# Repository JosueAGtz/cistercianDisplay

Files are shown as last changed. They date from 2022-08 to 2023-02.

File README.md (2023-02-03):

## Single color Cistercian Display
31 segments digital Cistercian Display with constant current serial to parallel driver. If you need more info please visit my blog https://savageelectronics.com/cistercian-display/

## RGB Cistercian Display
31 Segments RGB Cistercian Display with cascade SK6812 LEDs.

displayPhoto

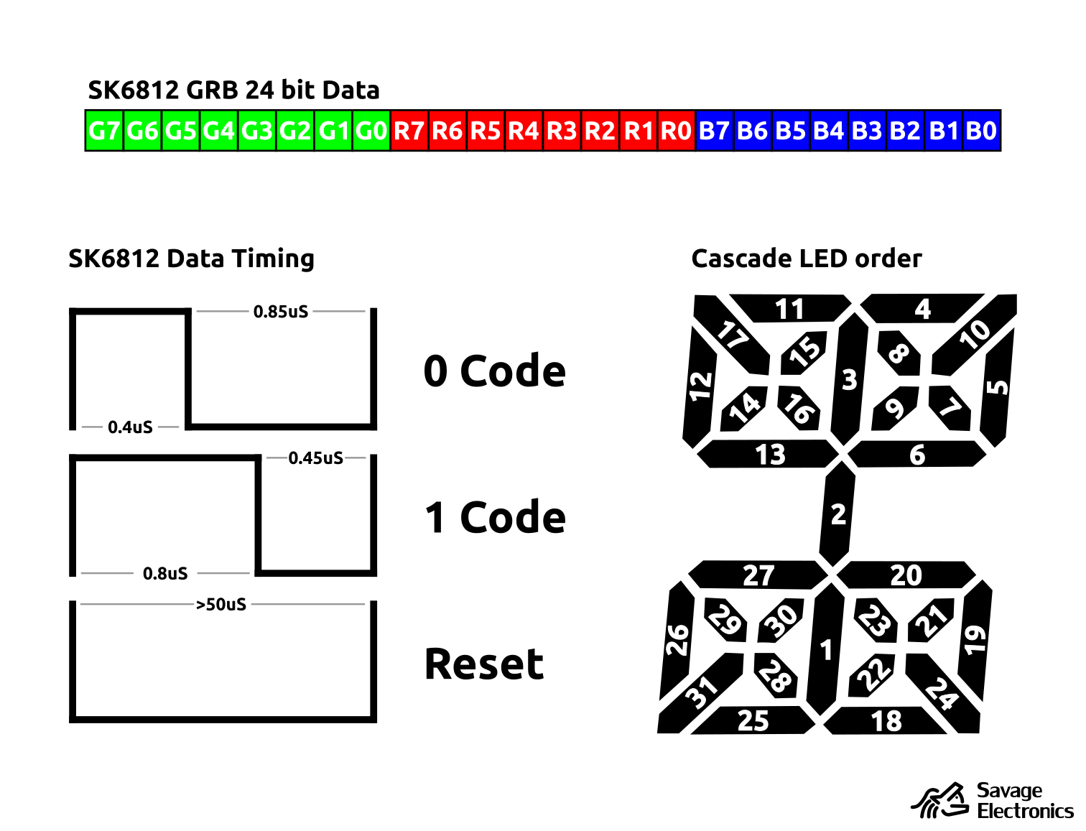
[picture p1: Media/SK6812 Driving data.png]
displayDriving


## Cistercian Display Decode
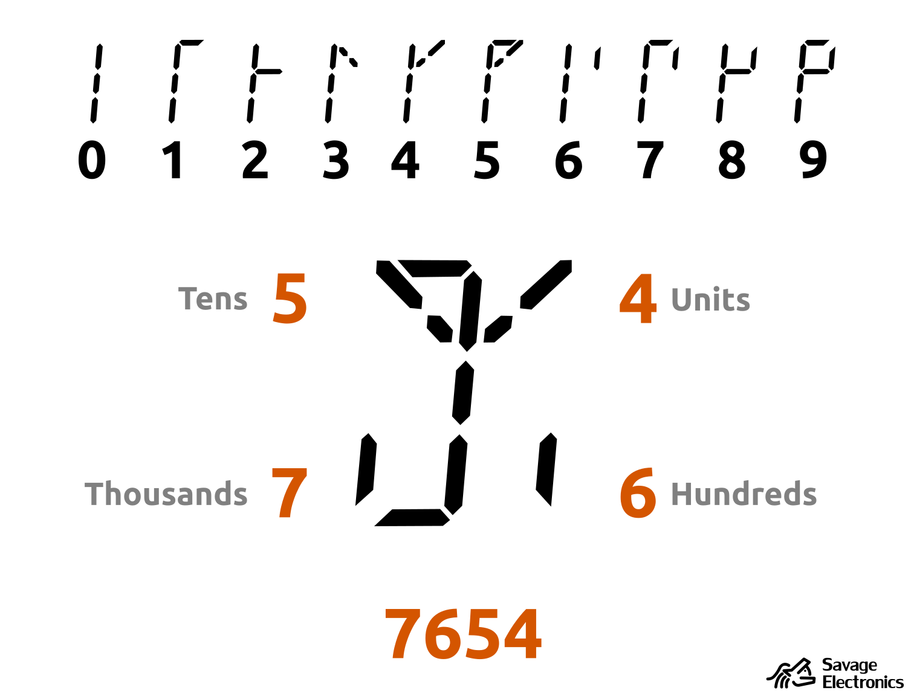
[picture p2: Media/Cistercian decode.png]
displayDecode


## RGB Cistercian Display Dimensions and Pinout
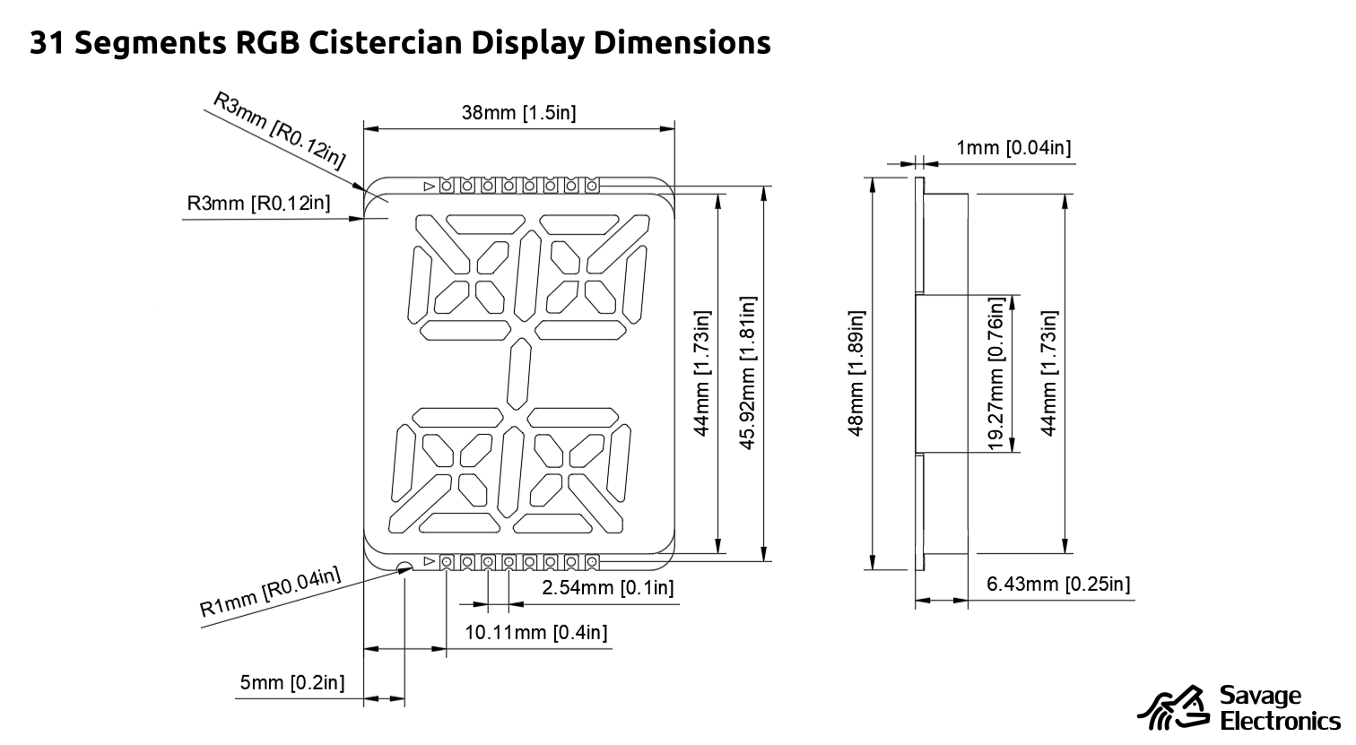
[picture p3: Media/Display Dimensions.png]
displayDimensions

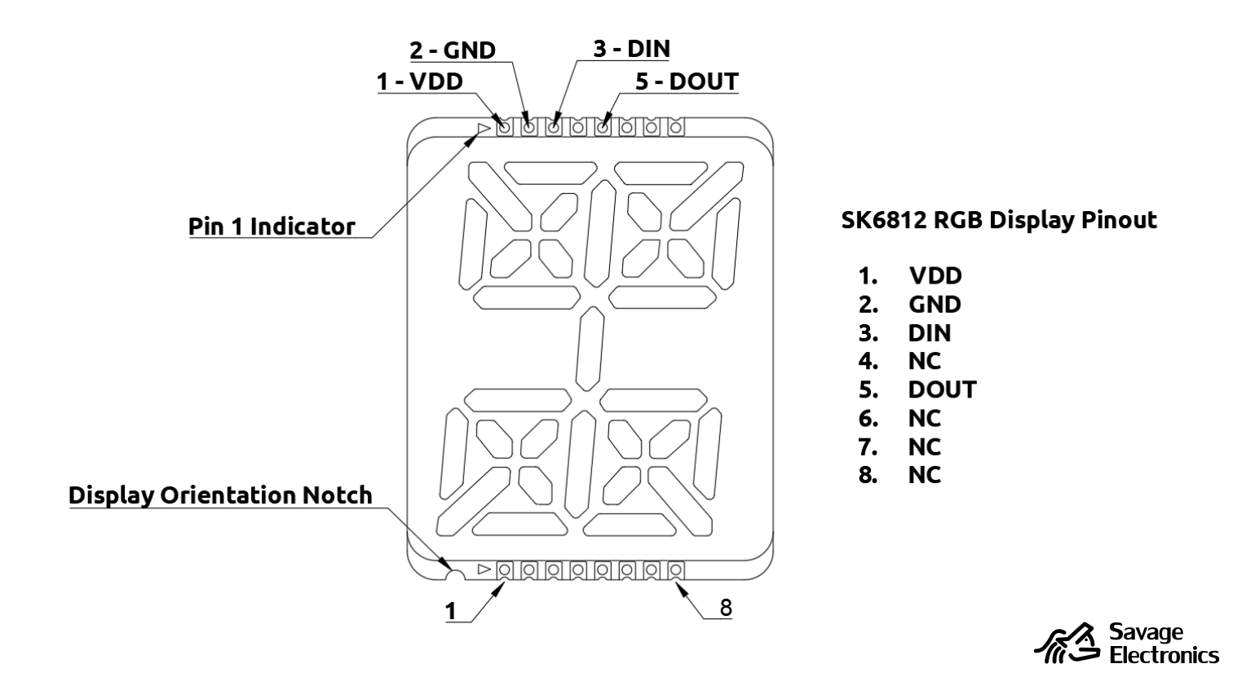
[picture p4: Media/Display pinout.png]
displayPinout


## Cistercian Display 3D Model
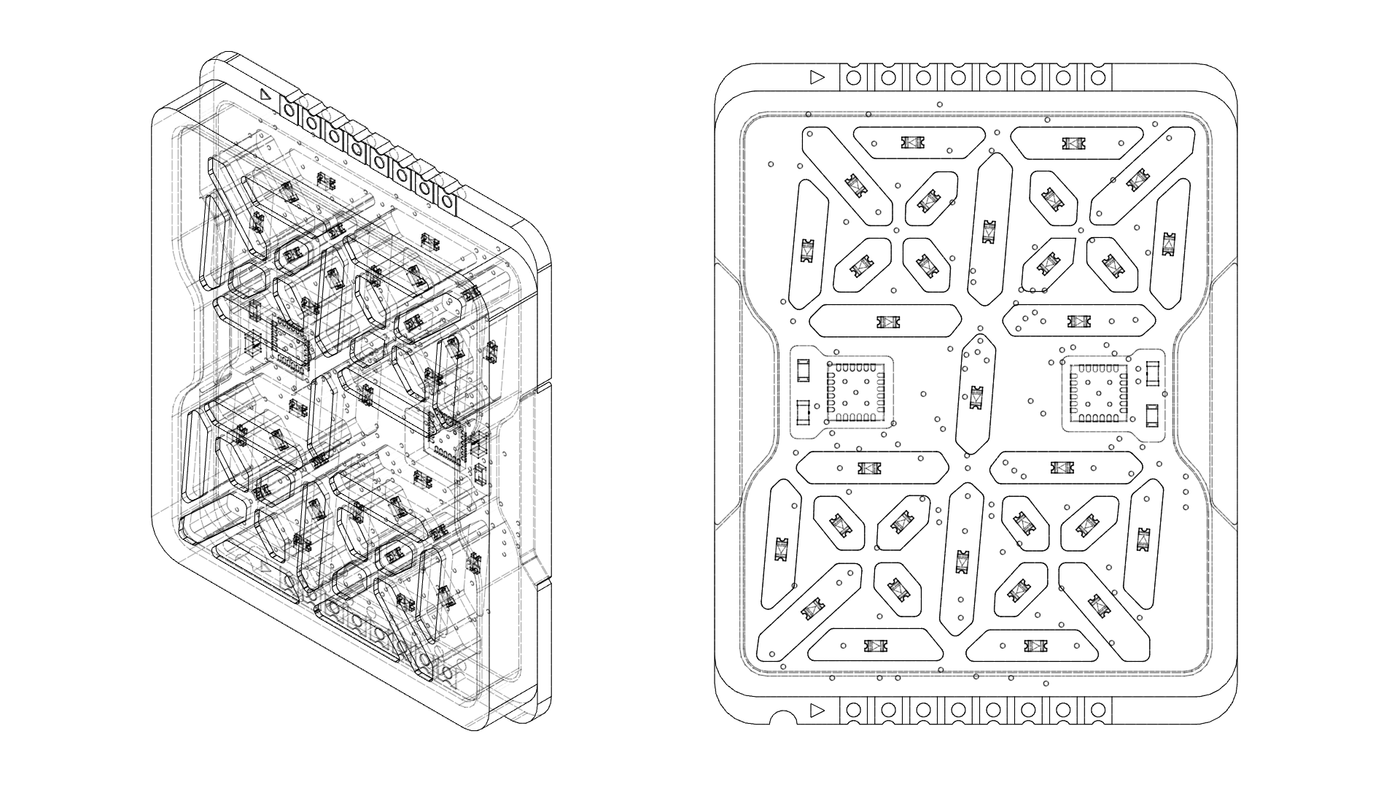
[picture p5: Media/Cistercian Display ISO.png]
displayISOMesh

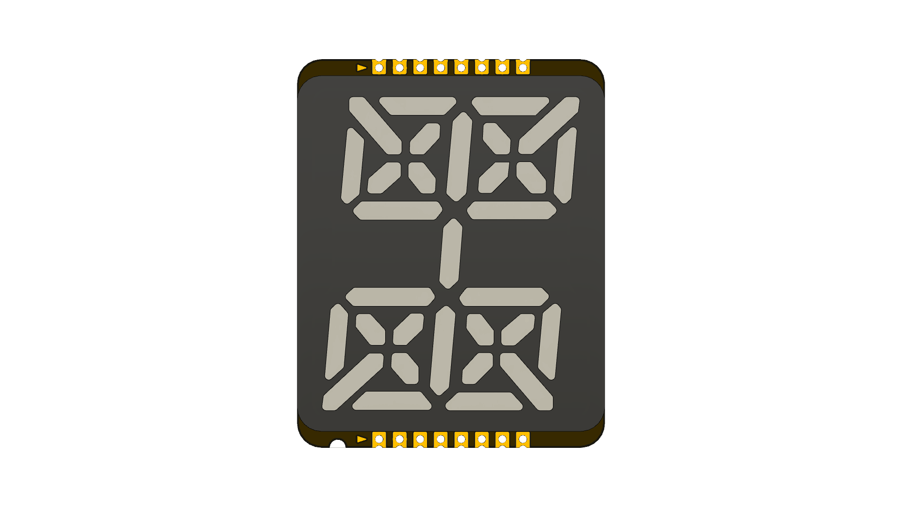
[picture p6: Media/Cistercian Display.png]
display3D


## Cistercian Display Schematic
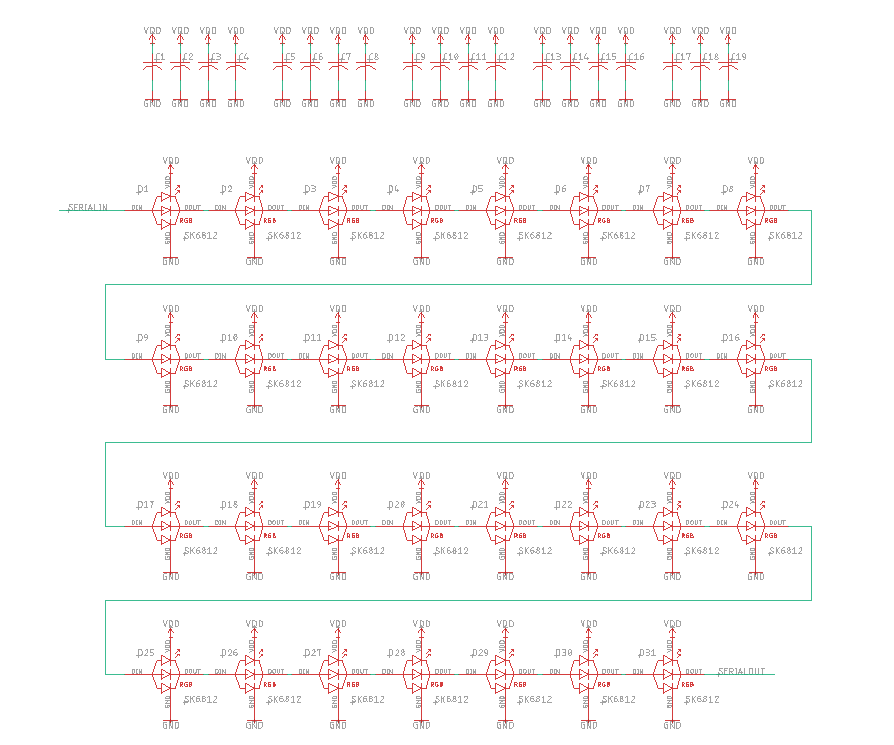
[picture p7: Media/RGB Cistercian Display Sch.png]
displayRGBSCH

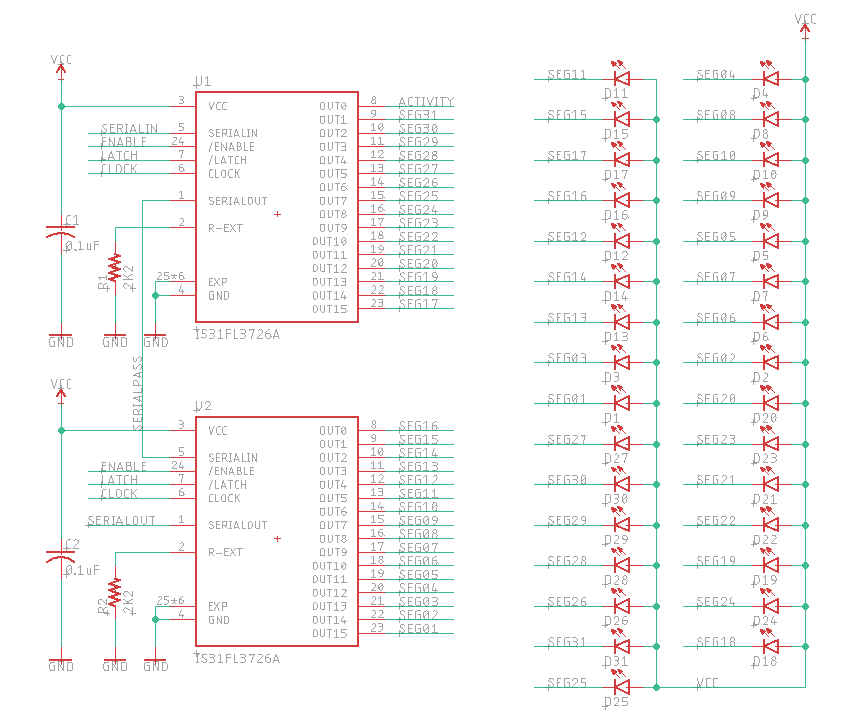
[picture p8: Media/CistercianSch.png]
displaySCH


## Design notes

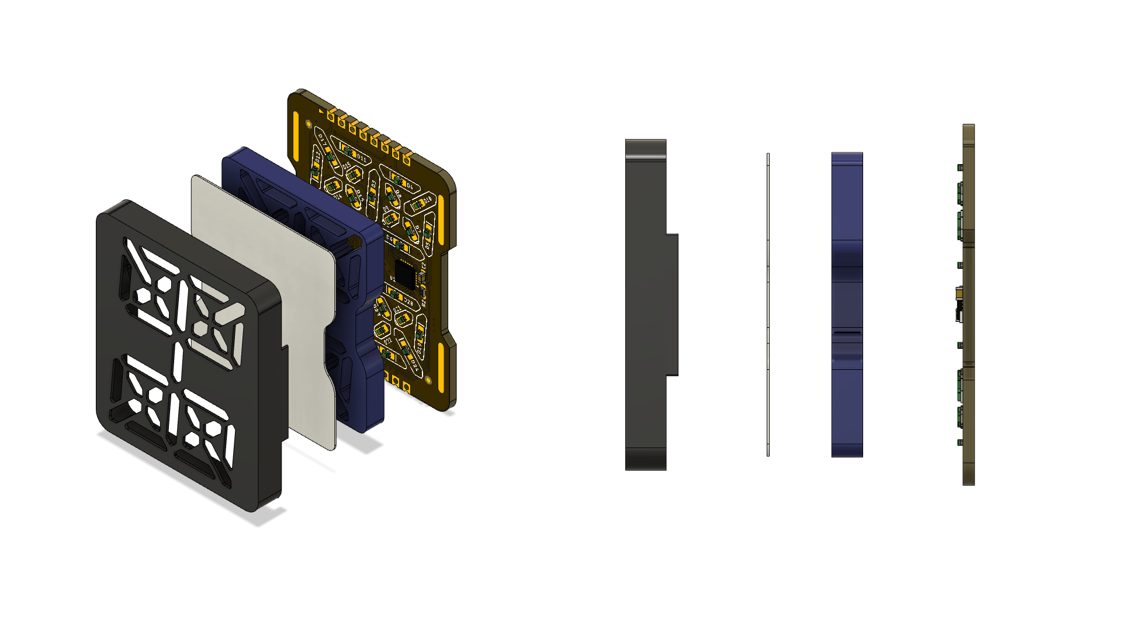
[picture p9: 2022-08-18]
Media/Cistercian Display Explode.png

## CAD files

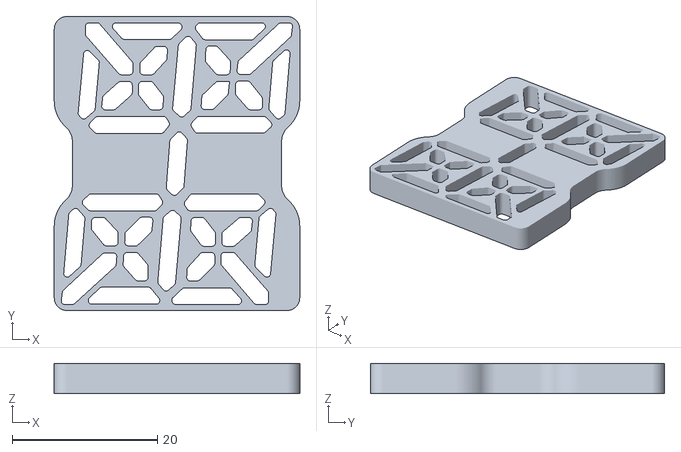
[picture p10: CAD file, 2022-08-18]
Hardware/CDisplay Spacer.stl
33.8 x 40.5 x 4.15

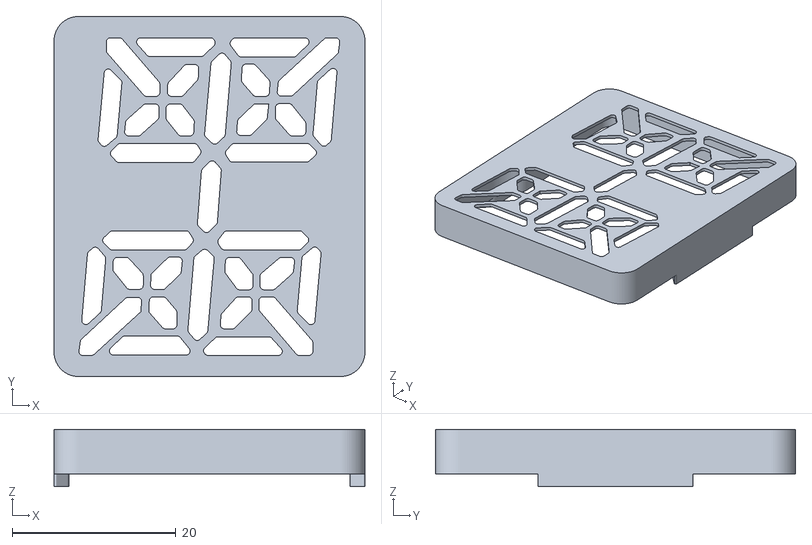
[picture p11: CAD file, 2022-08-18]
Hardware/CDisplay Body.stl
38.0 x 44.0 x 7.00

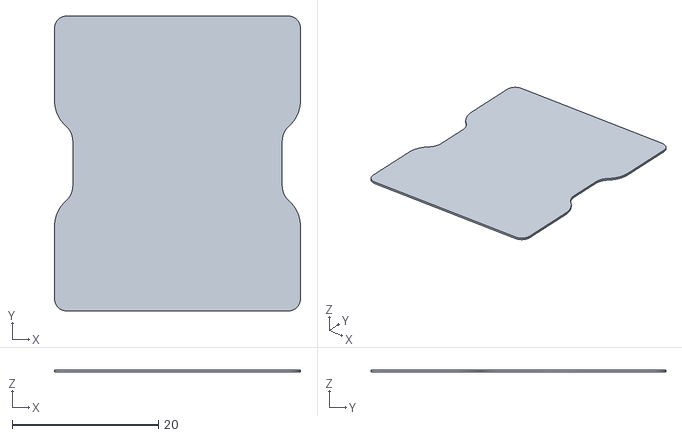
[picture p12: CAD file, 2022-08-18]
Hardware/CDisplay Diffuser.stl
33.6 x 40.3 x 0.32

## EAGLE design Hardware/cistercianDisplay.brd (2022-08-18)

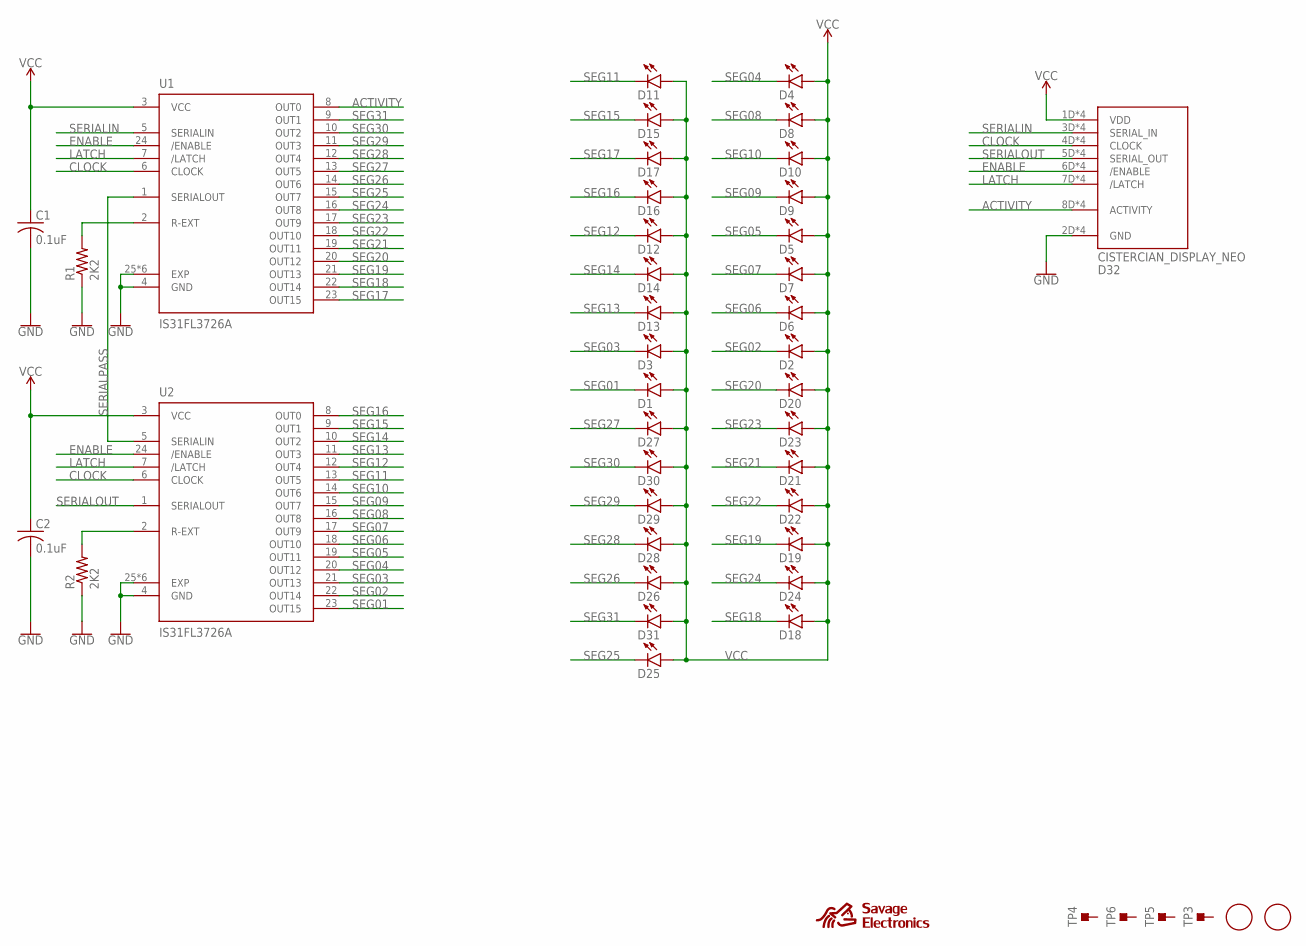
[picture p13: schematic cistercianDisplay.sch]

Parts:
C1, C2: 0.1uF; C0603
D1, D2, D3, D4, D5, D6, D7, D8, D9, D10, D11, D12, D13, D14, D15, D16, D17, D18, D19, D20, D21, D22, D23, D24, D25, D26, D27, D28, D29, D30, D31: LEDCHIP-LED0805; CHIP-LED0805
D32: CISTERCIAN_DISPLAY_NEO; CISTERCIAN_DISPLAYNEO
R1, R2: 2K2; R0603
TP3, TP4, TP5, TP6: TESTPOINT_TPS-SMD-10SN; TESTPOINT_SMD-10SN
U1, U2: IS31FL3726A; QFN50P400X400X90-25N
U$1, U$2: FIDUCIAL; FIDUCIAL_1MM
U$3: SE_SMALL_STOP

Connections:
ACTIVITY: D32.8D (ACTIVITY), D32.8DC (ACTIVITY), D32.8U (ACTIVITY), D32.8UC (ACTIVITY), U1.8 (OUT0)
CLOCK: D32.4D (CLOCK), D32.4DC (CLOCK), D32.4U (CLOCK), D32.4UC (CLOCK), U1.6 (CLOCK), U2.6 (CLOCK)
ENABLE: D32.6D (/ENABLE), D32.6DC (/ENABLE), D32.6U (/ENABLE), D32.6UC (/ENABLE), U1.24 (/ENABLE), U2.24 (/ENABLE)
GND: C1.2, C2.2, D32.2D (GND), D32.2DC (GND), D32.2U (GND), D32.2UC (GND), R1.1, R2.1, U1.4 (GND), U1.25 (EXP), U1.P$1 (EXP), U1.P$2 (EXP), U1.P$3 (EXP), U1.P$4 (EXP), U1.P$5 (EXP), U2.4 (GND), U2.25 (EXP), U2.P$1 (EXP), U2.P$2 (EXP), U2.P$3 (EXP), U2.P$4 (EXP), U2.P$5 (EXP)
LATCH: D32.7D (/LATCH), D32.7DC (/LATCH), D32.7U (/LATCH), D32.7UC (/LATCH), U1.7 (/LATCH), U2.7 (/LATCH)
unnamed: R2.2, U2.2 (R-EXT)
unnamed: R1.2, U1.2 (R-EXT)
SEG01: D1.C, U2.23 (OUT15)
SEG02: D2.C, U2.22 (OUT14)
SEG03: D3.C, U2.21 (OUT13)
SEG04: D4.C, U2.20 (OUT12)
SEG05: D5.C, U2.19 (OUT11)
SEG06: D6.C, U2.18 (OUT10)
SEG07: D7.C, U2.17 (OUT9)
SEG08: D8.C, U2.16 (OUT8)
SEG09: D9.C, U2.15 (OUT7)
SEG10: D10.C, U2.14 (OUT6)
SEG11: D11.C, U2.13 (OUT5)
SEG12: D12.C, U2.12 (OUT4)
SEG13: D13.C, U2.11 (OUT3)
SEG14: D14.C, U2.10 (OUT2)
SEG15: D15.C, U2.9 (OUT1)
SEG16: D16.C, U2.8 (OUT0)
SEG17: D17.C, U1.23 (OUT15)
SEG18: D18.C, U1.22 (OUT14)
SEG19: D19.C, U1.21 (OUT13)
SEG20: D20.C, U1.20 (OUT12)
SEG21: D21.C, U1.19 (OUT11)
SEG22: D22.C, U1.18 (OUT10)
SEG23: D23.C, U1.17 (OUT9)
SEG24: D24.C, U1.16 (OUT8)
SEG25: D25.C, U1.15 (OUT7)
SEG26: D26.C, U1.14 (OUT6)
SEG27: D27.C, U1.13 (OUT5)
SEG28: D28.C, U1.12 (OUT4)
SEG29: D29.C, U1.11 (OUT3)
SEG30: D30.C, U1.10 (OUT2)
SEG31: D31.C, U1.9 (OUT1)
SERIALIN: D32.3D (SERIAL_IN), D32.3DC (SERIAL_IN), D32.3U (SERIAL_IN), D32.3UC (SERIAL_IN), U1.5 (SERIALIN)
SERIALOUT: D32.5D (SERIAL_OUT), D32.5DC (SERIAL_OUT), D32.5U (SERIAL_OUT), D32.5UC (SERIAL_OUT), U2.1 (SERIALOUT)
SERIALPASS: U1.1 (SERIALOUT), U2.5 (SERIALIN)
VCC: C1.1, C2.1, D1.A, D2.A, D3.A, D4.A, D5.A, D6.A, D7.A, D8.A, D9.A, D10.A, D11.A, D12.A, D13.A, D14.A, D15.A, D16.A, D17.A, D18.A, D19.A, D20.A, D21.A, D22.A, D23.A, D24.A, D25.A, D26.A, D27.A, D28.A, D29.A, D30.A, D31.A, D32.1D (VDD), D32.1DC (VDD), D32.1U (VDD), D32.1UC (VDD), U1.3 (VCC), U2.3 (VCC)

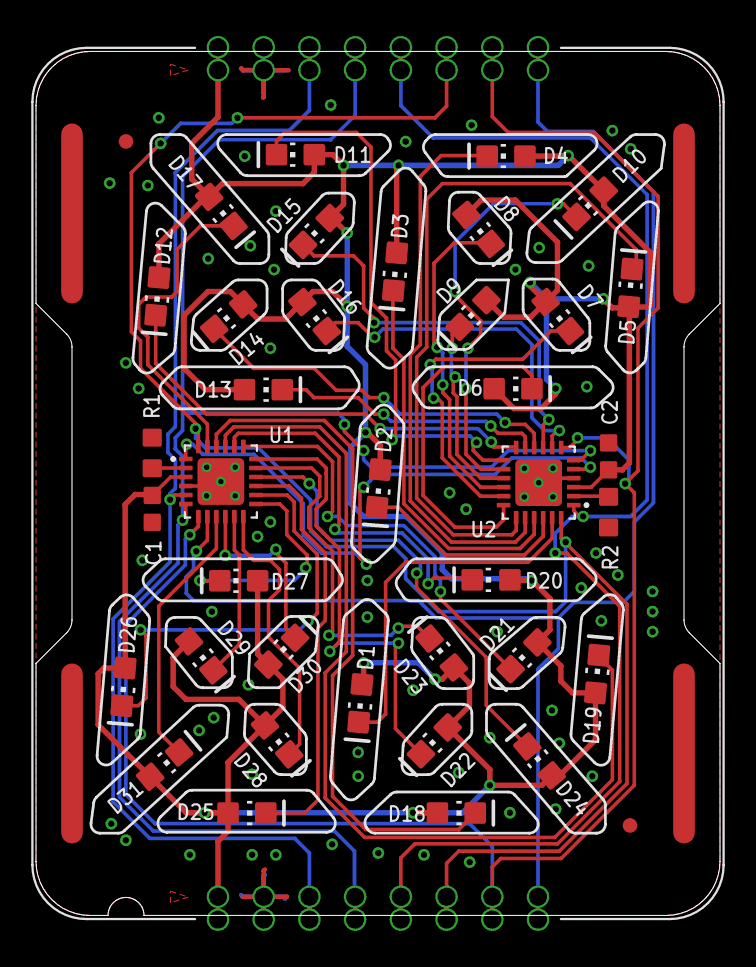
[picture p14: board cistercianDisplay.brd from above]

Board: 2 copper layers, 38.0 x 48.0 mm, 45 parts (1 on the bottom side), 42 nets.

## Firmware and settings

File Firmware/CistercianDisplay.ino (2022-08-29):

#include <WiFi.h>
#include <time.h>

#define SK6812LED 18

#define SERIAL_PIN 35
#define CLOCK_PIN 36
#define LATCH_PIN 33
#define ENABLE_PIN 34

#define HRS_LED 11
#define MIN_LED 10
#define MONTH_LED 9
#define DAY_LED 8
#define YEAR_LED 7

#define CLOCKCYCLES 3
#define UPDATERATE  2000

unsigned long requestDueTime;
unsigned int displayData = 1;
unsigned int turnOnClock = 0;
unsigned int prevMinutes = 0;
bool updateData;

const char *ntpServer = "pool.ntp.org";
const long gmtOffset_sec = -3600 * 6;
const int daylightOffset_sec = 3600;

const char *ssid     = "YourWifi";
const char *password = "YourPassword";

// 1 to 9 digit cistercian representation
// 1 2 3 4 5 6 7 8 9 10 11 12 13 14 15 16 17 18 19 20 21 22 23 24 25 26 27 28 29 30 31 32
bool numberUnits[10][32] = { { 1, 1, 1, 0, 0, 0, 0, 0, 0, 0, 0, 0, 0, 0, 0, 0, 0, 0, 0, 0, 0, 0, 0, 0, 0, 0, 0, 0, 0, 0, 0, 0 },    // 0
                             { 1, 1, 1, 1, 0, 0, 0, 0, 0, 0, 0, 0, 0, 0, 0, 0, 0, 0, 0, 0, 0, 0, 0, 0, 0, 0, 0, 0, 0, 0, 0, 0 },    // 1
                             { 1, 1, 1, 0, 0, 1, 0, 0, 0, 0, 0, 0, 0, 0, 0, 0, 0, 0, 0, 0, 0, 0, 0, 0, 0, 0, 0, 0, 0, 0, 0, 0 },    // 2
                             { 1, 1, 1, 0, 0, 0, 1, 1, 0, 0, 0, 0, 0, 0, 0, 0, 0, 0, 0, 0, 0, 0, 0, 0, 0, 0, 0, 0, 0, 0, 0, 0 },    // 3
                             { 1, 1, 1, 0, 0, 0, 0, 0, 1, 1, 0, 0, 0, 0, 0, 0, 0, 0, 0, 0, 0, 0, 0, 0, 0, 0, 0, 0, 0, 0, 0, 0 },    // 4
                             { 1, 1, 1, 1, 0, 0, 0, 0, 1, 1, 0, 0, 0, 0, 0, 0, 0, 0, 0, 0, 0, 0, 0, 0, 0, 0, 0, 0, 0, 0, 0, 0 },    // 5
                             { 1, 1, 1, 0, 1, 0, 0, 0, 0, 0, 0, 0, 0, 0, 0, 0, 0, 0, 0, 0, 0, 0, 0, 0, 0, 0, 0, 0, 0, 0, 0, 0 },    // 6
                             { 1, 1, 1, 1, 1, 0, 0, 0, 0, 0, 0, 0, 0, 0, 0, 0, 0, 0, 0, 0, 0, 0, 0, 0, 0, 0, 0, 0, 0, 0, 0, 0 },    // 7
                             { 1, 1, 1, 0, 1, 1, 0, 0, 0, 0, 0, 0, 0, 0, 0, 0, 0, 0, 0, 0, 0, 0, 0, 0, 0, 0, 0, 0, 0, 0, 0, 0 },    // 8
                             { 1, 1, 1, 1, 1, 1, 0, 0, 0, 0, 0, 0, 0, 0, 0, 0, 0, 0, 0, 0, 0, 0, 0, 0, 0, 0, 0, 0, 0, 0, 0, 0 } };  // 9

// 1 2 3 4 5 6 7 8 9 10 11 12 13 14 15 16 17 18 19 20 21 22 23 24 25 26 27 28 29 30 31 32
bool numberTens[10][32] = { { 1, 1, 1, 0, 0, 0, 0, 0, 0, 0, 0, 0, 0, 0, 0, 0, 0, 0, 0, 0, 0, 0, 0, 0, 0, 0, 0, 0, 0, 0, 0, 0 },    // 0
                            { 1, 1, 1, 0, 0, 0, 0, 0, 0, 0, 1, 0, 0, 0, 0, 0, 0, 0, 0, 0, 0, 0, 0, 0, 0, 0, 0, 0, 0, 0, 0, 0 },    // 1
                            { 1, 1, 1, 0, 0, 0, 0, 0, 0, 0, 0, 0, 1, 0, 0, 0, 0, 0, 0, 0, 0, 0, 0, 0, 0, 0, 0, 0, 0, 0, 0, 0 },    // 2
                            { 1, 1, 1, 0, 0, 0, 0, 0, 0, 0, 0, 0, 0, 1, 1, 0, 0, 0, 0, 0, 0, 0, 0, 0, 0, 0, 0, 0, 0, 0, 0, 0 },    // 3
                            { 1, 1, 1, 0, 0, 0, 0, 0, 0, 0, 0, 0, 0, 0, 0, 1, 1, 0, 0, 0, 0, 0, 0, 0, 0, 0, 0, 0, 0, 0, 0, 0 },    // 4
                            { 1, 1, 1, 0, 0, 0, 0, 0, 0, 0, 1, 0, 0, 0, 0, 1, 1, 0, 0, 0, 0, 0, 0, 0, 0, 0, 0, 0, 0, 0, 0, 0 },    // 5
                            { 1, 1, 1, 0, 0, 0, 0, 0, 0, 0, 0, 1, 0, 0, 0, 0, 0, 0, 0, 0, 0, 0, 0, 0, 0, 0, 0, 0, 0, 0, 0, 0 },    // 6
                            { 1, 1, 1, 0, 0, 0, 0, 0, 0, 0, 1, 1, 0, 0, 0, 0, 0, 0, 0, 0, 0, 0, 0, 0, 0, 0, 0, 0, 0, 0, 0, 0 },    // 7
                            { 1, 1, 1, 0, 0, 0, 0, 0, 0, 0, 0, 1, 1, 0, 0, 0, 0, 0, 0, 0, 0, 0, 0, 0, 0, 0, 0, 0, 0, 0, 0, 0 },    // 8
                            { 1, 1, 1, 0, 0, 0, 0, 0, 0, 0, 1, 1, 1, 0, 0, 0, 0, 0, 0, 0, 0, 0, 0, 0, 0, 0, 0, 0, 0, 0, 0, 0 } };  // 9

// 1 2 3 4 5 6 7 8 9 10 11 12 13 14 15 16 17 18 19 20 21 22 23 24 25 26 27 28 29 30 31 32
bool numberHundreds[10][32] = { { 1, 1, 1, 0, 0, 0, 0, 0, 0, 0, 0, 0, 0, 0, 0, 0, 0, 0, 0, 0, 0, 0, 0, 0, 0, 0, 0, 0, 0, 0, 0, 0 },    // 0
                                { 1, 1, 1, 0, 0, 0, 0, 0, 0, 0, 0, 0, 0, 0, 0, 0, 0, 1, 0, 0, 0, 0, 0, 0, 0, 0, 0, 0, 0, 0, 0, 0 },    // 1
                                { 1, 1, 1, 0, 0, 0, 0, 0, 0, 0, 0, 0, 0, 0, 0, 0, 0, 0, 0, 1, 0, 0, 0, 0, 0, 0, 0, 0, 0, 0, 0, 0 },    // 2
                                { 1, 1, 1, 0, 0, 0, 0, 0, 0, 0, 0, 0, 0, 0, 0, 0, 0, 0, 0, 0, 1, 1, 0, 0, 0, 0, 0, 0, 0, 0, 0, 0 },    // 3
                                { 1, 1, 1, 0, 0, 0, 0, 0, 0, 0, 0, 0, 0, 0, 0, 0, 0, 0, 0, 0, 0, 0, 1, 1, 0, 0, 0, 0, 0, 0, 0, 0 },    // 4
                                { 1, 1, 1, 0, 0, 0, 0, 0, 0, 0, 0, 0, 0, 0, 0, 0, 0, 1, 0, 0, 0, 0, 1, 1, 0, 0, 0, 0, 0, 0, 0, 0 },    // 5
                                { 1, 1, 1, 0, 0, 0, 0, 0, 0, 0, 0, 0, 0, 0, 0, 0, 0, 0, 1, 0, 0, 0, 0, 0, 0, 0, 0, 0, 0, 0, 0, 0 },    // 6
                                { 1, 1, 1, 0, 0, 0, 0, 0, 0, 0, 0, 0, 0, 0, 0, 0, 0, 1, 1, 0, 0, 0, 0, 0, 0, 0, 0, 0, 0, 0, 0, 0 },    // 7
                                { 1, 1, 1, 0, 0, 0, 0, 0, 0, 0, 0, 0, 0, 0, 0, 0, 0, 0, 1, 1, 0, 0, 0, 0, 0, 0, 0, 0, 0, 0, 0, 0 },    // 8
                                { 1, 1, 1, 0, 0, 0, 0, 0, 0, 0, 0, 0, 0, 0, 0, 0, 0, 1, 1, 1, 0, 0, 0, 0, 0, 0, 0, 0, 0, 0, 0, 0 } };  // 9

// 1 2 3 4 5 6 7 8 9 10 11 12 13 14 15 16 17 18 19 20 21 22 23 24 25 26 27 28 29 30 31 32
bool numberThousands[10][32] = { { 1, 1, 1, 0, 0, 0, 0, 0, 0, 0, 0, 0, 0, 0, 0, 0, 0, 0, 0, 0, 0, 0, 0, 0, 0, 0, 0, 0, 0, 0, 0, 0 },    // 0
                                 { 1, 1, 1, 0, 0, 0, 0, 0, 0, 0, 0, 0, 0, 0, 0, 0, 0, 0, 0, 0, 0, 0, 0, 0, 1, 0, 0, 0, 0, 0, 0, 0 },    // 1
                                 { 1, 1, 1, 0, 0, 0, 0, 0, 0, 0, 0, 0, 0, 0, 0, 0, 0, 0, 0, 0, 0, 0, 0, 0, 0, 0, 1, 0, 0, 0, 0, 0 },    // 2
                                 { 1, 1, 1, 0, 0, 0, 0, 0, 0, 0, 0, 0, 0, 0, 0, 0, 0, 0, 0, 0, 0, 0, 0, 0, 0, 0, 0, 1, 1, 0, 0, 0 },    // 3
                                 { 1, 1, 1, 0, 0, 0, 0, 0, 0, 0, 0, 0, 0, 0, 0, 0, 0, 0, 0, 0, 0, 0, 0, 0, 0, 0, 0, 0, 0, 1, 1, 0 },    // 4
                                 { 1, 1, 1, 0, 0, 0, 0, 0, 0, 0, 0, 0, 0, 0, 0, 0, 0, 0, 0, 0, 0, 0, 0, 0, 1, 0, 0, 0, 0, 1, 1, 0 },    // 5
                                 { 1, 1, 1, 0, 0, 0, 0, 0, 0, 0, 0, 0, 0, 0, 0, 0, 0, 0, 0, 0, 0, 0, 0, 0, 0, 1, 0, 0, 0, 0, 0, 0 },    // 6
                                 { 1, 1, 1, 0, 0, 0, 0, 0, 0, 0, 0, 0, 0, 0, 0, 0, 0, 0, 0, 0, 0, 0, 0, 0, 1, 1, 0, 0, 0, 0, 0, 0 },    // 7
                                 { 1, 1, 1, 0, 0, 0, 0, 0, 0, 0, 0, 0, 0, 0, 0, 0, 0, 0, 0, 0, 0, 0, 0, 0, 0, 1, 1, 0, 0, 0, 0, 0 },    // 8
                                 { 1, 1, 1, 0, 0, 0, 0, 0, 0, 0, 0, 0, 0, 0, 0, 0, 0, 0, 0, 0, 0, 0, 0, 0, 1, 1, 1, 0, 0, 0, 0, 0 } };  // 9

void setDigit(int digit);
struct tm timeinfo;

void setup() {
  Serial.begin(115200);

  pinMode(ENABLE_PIN, OUTPUT);
  pinMode(SERIAL_PIN, OUTPUT);
  pinMode(CLOCK_PIN, OUTPUT);
  pinMode(LATCH_PIN, OUTPUT);

  pinMode(MONTH_LED, OUTPUT);
  pinMode(DAY_LED, OUTPUT);
  pinMode(YEAR_LED, OUTPUT);
  pinMode(HRS_LED, OUTPUT);
  pinMode(MIN_LED, OUTPUT);

  digitalWrite(HRS_LED, LOW);
  digitalWrite(MIN_LED, LOW);
  digitalWrite(MONTH_LED, LOW);
  digitalWrite(DAY_LED, LOW);
  digitalWrite(YEAR_LED, LOW);
  digitalWrite(ENABLE_PIN, HIGH);

  uint8_t wifiConectionAttmps = 0;

  WiFi.begin(ssid, password);
  Serial.print("Connecting to ");
  Serial.print(ssid);
  while (WiFi.status() != WL_CONNECTED & wifiConectionAttmps < 20) {
    delay(500);
    Serial.print(".");
    wifiConectionAttmps++;
  }

  configTime(gmtOffset_sec, daylightOffset_sec, ntpServer);

  digitalWrite(HRS_LED, HIGH);
  digitalWrite(MIN_LED, HIGH);
  digitalWrite(MONTH_LED, HIGH);
  digitalWrite(DAY_LED, HIGH);
  digitalWrite(YEAR_LED, HIGH);

  digitalWrite(ENABLE_PIN, LOW);

  setDigit(1111);
  delay(250);
  setDigit(2222);
  delay(250);
  setDigit(3333);
  delay(250);
  setDigit(4444);
  delay(250);
  setDigit(5555);
  delay(250);
  setDigit(6666);
  delay(250);
  setDigit(7777);
  delay(250);
  setDigit(8888);
  delay(250);
  setDigit(9999);
  delay(250);
  setDigit(0000);
  delay(250);
  digitalWrite(HRS_LED, LOW);
  digitalWrite(MIN_LED, LOW);
  digitalWrite(MONTH_LED, LOW);
  digitalWrite(DAY_LED, LOW);
  digitalWrite(YEAR_LED, LOW);
}

void loop() {
  getLocalTime(&timeinfo);

  if (prevMinutes != timeinfo.tm_min) {  // Display Clocl for a couple of cycles every minute
    turnOnClock = 0;
    prevMinutes = timeinfo.tm_min;
  }

  if (millis() > requestDueTime) {  // Update clock data every 2 seconds
    updateData = 1;
    requestDueTime = millis() + UPDATERATE;
  }

  if (updateData == 1) {
    switch (displayData++) {
      case 1:
        if (turnOnClock <= (CLOCKCYCLES)) {
          turnOnClock++;
          digitalWrite(ENABLE_PIN, LOW);
          Serial.print("Clock cycle: ");
          Serial.println(turnOnClock);
        }

        if (turnOnClock > (CLOCKCYCLES) ) {
          digitalWrite(ENABLE_PIN, HIGH);
          Serial.println("Display Power off!");
        }

        digitalWrite(YEAR_LED, LOW);
        digitalWrite(HRS_LED, HIGH);
        setDigit(timeinfo.tm_hour);
        Serial.print(" Hour: ");
        Serial.print(timeinfo.tm_hour);
        break;
      case 2:
        digitalWrite(HRS_LED, LOW);
        digitalWrite(MIN_LED, HIGH);
        setDigit(timeinfo.tm_min);
        Serial.print("  Minute: ");
        Serial.print(timeinfo.tm_min);
        break;
      case 3:
        digitalWrite(MIN_LED, LOW);
        digitalWrite(MONTH_LED, HIGH);
        setDigit(timeinfo.tm_mon + 1);
        Serial.print("  Month: ");
        Serial.print(timeinfo.tm_mon + 1);
        break;
      case 4:
        digitalWrite(MONTH_LED, LOW);
        digitalWrite(DAY_LED, HIGH);
        setDigit(timeinfo.tm_mday);
        Serial.print("  Day: ");
        Serial.print(timeinfo.tm_mday);
        break;
      case 5:
        digitalWrite(DAY_LED, LOW);
        digitalWrite(YEAR_LED, HIGH);
        setDigit(timeinfo.tm_year + 1900);
        Serial.print("  Year: ");
        Serial.println(timeinfo.tm_year + 1900);
        break;
      default:
        setDigit(9999);
        break;
    }
    updateData = 0;
    if (displayData > 5)
      displayData = 1;
  }
}

void setDigit(int digit) {
  if (digit > 9999) digit = 0;
  int thousands = digit / 1000;
  int hundreds = (digit - (thousands * 1000)) / 100;
  int tens = (digit - (thousands * 1000) - (hundreds * 100)) / 10;
  int units = digit - (thousands * 1000) - (hundreds * 100) - (tens * 10);

  digitalWrite(LATCH_PIN, HIGH);
  for (int i = 0; i < 32; i++) {
    digitalWrite(CLOCK_PIN, LOW);
    digitalWrite(SERIAL_PIN, numberThousands[thousands][i] | numberHundreds[hundreds][i] | numberTens[tens][i] | numberUnits[units][i]);
    digitalWrite(CLOCK_PIN, HIGH);
  }
  digitalWrite(LATCH_PIN, LOW);
}

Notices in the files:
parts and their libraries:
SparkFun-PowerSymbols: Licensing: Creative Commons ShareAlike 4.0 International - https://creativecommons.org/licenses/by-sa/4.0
